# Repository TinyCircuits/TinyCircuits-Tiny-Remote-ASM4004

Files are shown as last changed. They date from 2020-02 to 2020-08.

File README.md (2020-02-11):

# TinyCircuits Tiny Remote ASM4004

The design files are located under design_files/ for the TinyCircuits ASM4004. This is a tiny remote that is used in the [TinyTV Kit](https://tinycircuits.com/products/tinytv-diy-kit), or as a standalone usable remote with pre-defined IR button codes. 
Format is in Cadsoft Eagle format - Eagle version 6.2 was used for the original design.

For more infomation on this, [check out the product page at TinyCircuits.com](https://tinycircuits.com/products/tiny-remote)

# License:

Design by [TinyCircuits](https://tinycircuits.com/).
All design files are released under the Creative Commons Attribution Share-Alike 3.0 License, see the following link for details: http://creativecommons.org/licenses/by-sa/3.0

All text above must be included in any redistribution or derived design

This project uses designs and concepts developed as part of the Arduino project and the LilyPad project.  The TinyCircuits design files themselves (schematics, PCB and libraries) are not directly derived from these works' design files and have been created new, however the concepts and basic architecture behind the TinyDuino and TinyLily products are derived and we thank the hard work of the organizations below for their contributions to open-source hardware:
  
Original Arduino Uno Design by Team Arduino

LilyPad Arduino Design by Leah Buechley and Sparkfun Electronics

Please support the open-source hardware community

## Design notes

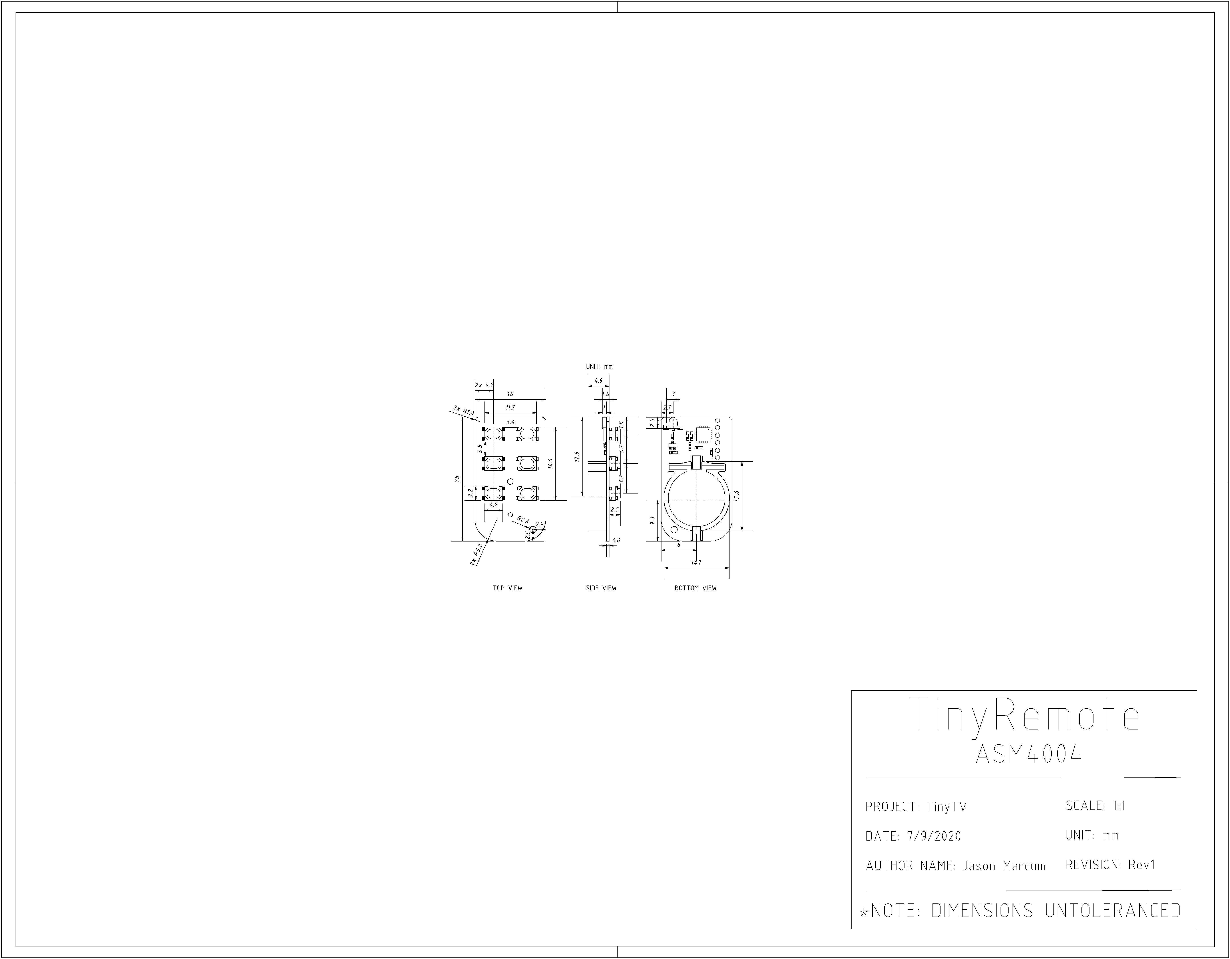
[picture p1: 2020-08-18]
cad/TinyRemote_ASM4004_REV1-DETAILED_DRAWING-PNG.png

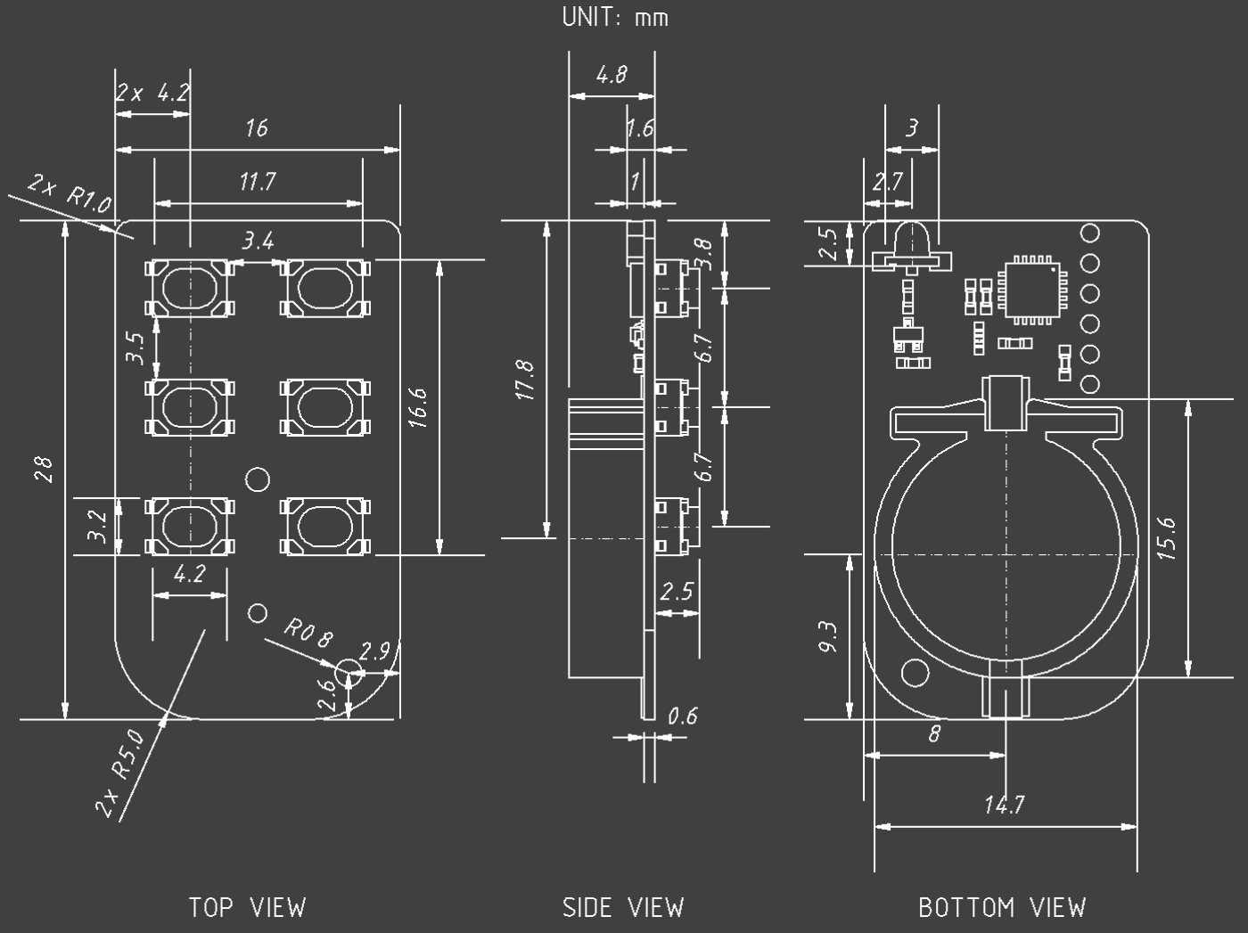
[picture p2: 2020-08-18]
cad/TinyRemote_ASM4004_REV1-DETAILED_DRAWING_COMPACT-PNG.png

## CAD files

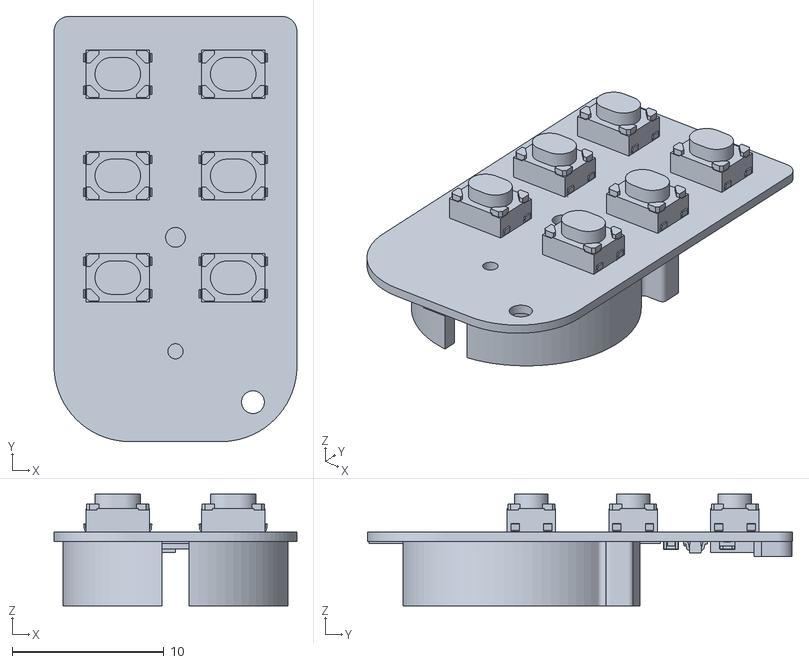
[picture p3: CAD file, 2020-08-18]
cad/TinyRemote_ASM4004_REV1-STL.stl
16.0 x 28.0 x 7.35

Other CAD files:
cad/TinyRemote_ASM4004_REV1-DETAILED_DRAWING-DXF.dxf

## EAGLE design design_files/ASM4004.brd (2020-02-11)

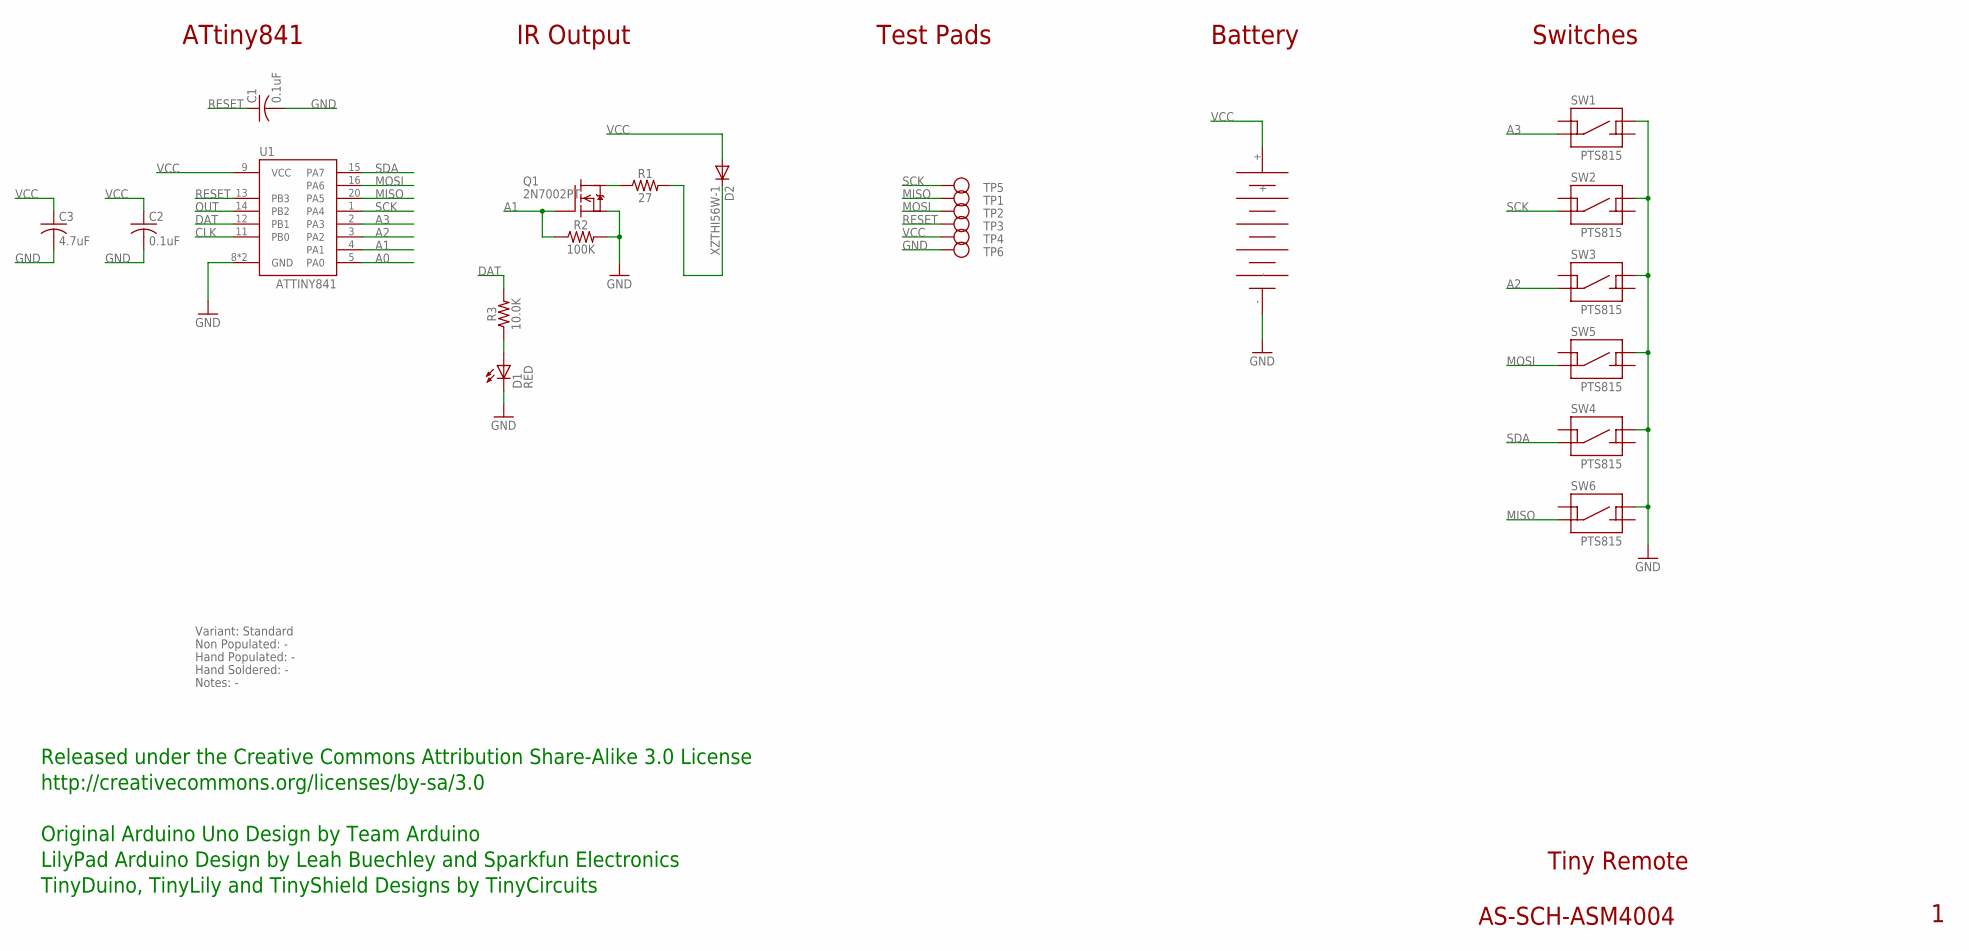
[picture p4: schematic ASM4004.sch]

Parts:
C1: 0.1uF; C0402; PARTNO AS-ITM-00008
C2: 0.1uF; C0402
C3: 4.7uF; C0402; PARTNO AS-ITM-00242
D1: RED; 0402_LED; PARTNO AS-ITM-00057
D2: XZTHI56W-1; LED_SIDE_3.0X1.0; PARTNO AS-ITM-00551
J2: 1225; COIN_1220_SMD; PARTNO AS-ITM-00468
Q1: 2N7002PT; SOT-416
R1: 27; 0402; PARTNO AS-ITM-00240
R2: 100K; 0402
R3: 10.0K; 0402; PARTNO AS-ITM-00032
SW1, SW2, SW3, SW4, SW5, SW6: PTS815; PARTNO AS-ITM-00544
TP1, TP2, TP3, TP4, TP5, TP6: TEST_POINT; TEST_POINT_1MM
U1: ATTINY841; VQFN-20

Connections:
A0: U1.5 (PA0)
A1: Q1.1 (G), R2.1, U1.4 (PA1)
A2: SW3.1, U1.3 (PA2)
A3: SW1.1, U1.2 (PA3)
CLK: U1.11 (PB0)
DAT: R3.2, U1.12 (PB1)
GND: C1.2, C2.2, C3.2, D1.2 (C), J2.-, Q1.2 (S), R2.2, SW1.4, SW2.4, SW3.4, SW4.4, SW5.4, SW6.4, TP6.P$1, U1.8 (GND), U1.PAD (GND)
MISO: SW6.1, TP1.P$1, U1.20 (PA5)
MOSI: SW5.1, TP2.P$1, U1.16 (PA6)
unnamed: Q1.3 (D), R1.1
unnamed: D2.C, R1.2
unnamed: D1.1 (A), R3.1
OUT: U1.14 (PB2)
RESET: C1.1, TP3.P$1, U1.13 (PB3)
SCK: SW2.1, TP5.P$1, U1.1 (PA4)
SDA: SW4.1, U1.15 (PA7)
VCC: C2.1, C3.1, D2.A, J2.+, TP4.P$1, U1.9 (VCC)

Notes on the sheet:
Tiny Remote
AS-SCH-ASM4004
Test Pads
ATtiny841
Battery
IR Output
Variant: Standard
Non Populated: -
Hand Populated: -
Hand Soldered: -
Notes: -
Switches
Released under the Creative Commons Attribution Share-Alike 3.0 License
http://creativecommons.org/licenses/by-sa/3.0
Original Arduino Uno Design by Team Arduino
TinyDuino, TinyLily and TinyShield Designs by TinyCircuits
LilyPad Arduino Design by Leah Buechley and Sparkfun Electronics

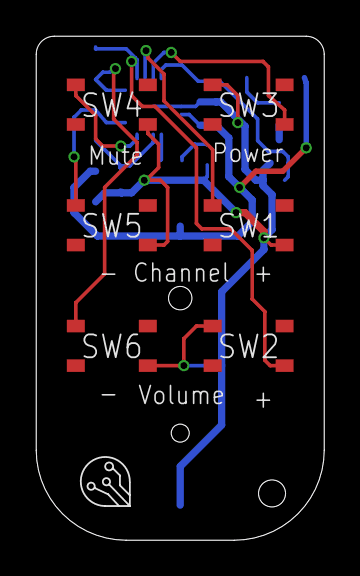
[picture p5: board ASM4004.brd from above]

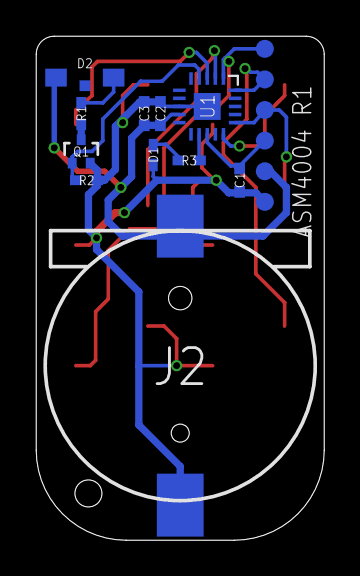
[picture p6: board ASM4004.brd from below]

Board: 2 copper layers, 16.0 x 28.0 mm, 24 parts (17 on the bottom side), 14 nets.

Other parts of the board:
U$1: DOCFIELD-TINYCIRCUITS-PCB

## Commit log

2020-06-26 Add CAD data
2020-06-30 Rename files, add dxf, and use new 2D drawing template
    [TinyRemote_ASM4004_DXF_REV1.dxf]
2020-07-01 Remove vias in models and drawings, add compact dimension images, and remove a file to reduce size
    [TinyRemote_ASM4004_DXF_REV1.dxf, TinyRemote_DXF_ASM4004_REV1.dxf, TinyRemote_STL_ASM4004_REV1.stl]
2020-07-02 Add zip of all CAD files
2020-08-18 Update CAD drawings
    [TinyRemote_ASM4004_REV1-DETAILED_DRAWING-DXF.dxf, TinyRemote_ASM4004_REV1-STL.stl, TinyRemote_DXF_ASM4004_REV1.dxf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]
